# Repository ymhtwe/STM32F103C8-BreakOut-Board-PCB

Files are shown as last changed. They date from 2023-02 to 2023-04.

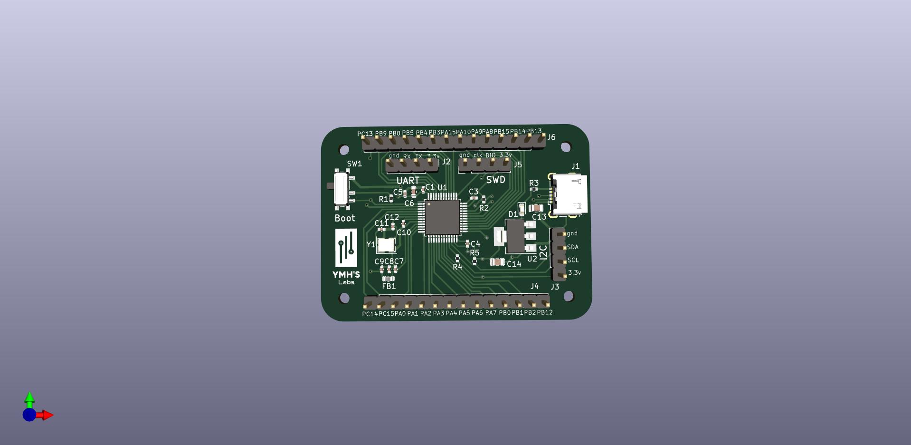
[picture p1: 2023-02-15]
STM32F103C8T6_BreakOut_Board/Docs/STM32 Based 3D.jpg

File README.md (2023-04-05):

# STM32F103C8-BreakOut-Board-PCB 

This repository contains the design files for a breakout board for the STM32F103C8T6 microcontroller in a 48-pin LQFP package. The breakout board provides easy access to all the pins of the microcontroller, as well as a USB-to-serial converter for programming and debugging.

Features
Compact breakout board for the STM32F103C8T6 microcontroller
All pins of the microcontroller are accessible via headers
Onboard 3.3V voltage regulator and decoupling capacitors
USB-to-serial converter for programming and debugging
Bootloader mode for easy firmware updates
Getting started
To get started with the STM32F103C8 Breakout Board PCB, you will need the following:

STM32F103C8T6 microcontroller (not included)
USB-to-serial cable (not included)
Development environment (e.g., STM32CubeIDE, Keil, or Arduino IDE)
To program and debug the microcontroller, connect the USB-to-serial cable to the J1 header on the breakout board, and connect the other end of the cable to your computer. Open your development environment and select the appropriate settings for the microcontroller and programming interface. You can then program and debug your firmware as usual.

Repository contents
Gerber/: Gerber files for manufacturing the PCB
Schematic/: Schematic and BOM for the PCB design
Hardware/: PCB layout design files in KiCad format
License
The STM32F103C8 Breakout Board PCB is released under the MIT License. See the LICENSE file for more details.

Credits
The STM32F103C8 Breakout Board PCB was designed by Ye Min Htwe. If you have any questions or feedback, please open an issue on GitHub.

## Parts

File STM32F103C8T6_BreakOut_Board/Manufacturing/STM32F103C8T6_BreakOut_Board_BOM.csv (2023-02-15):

Source: | E:\KiCad\Projects\STM32F103C8T6_BreakOut_Board\STM32F103C8T6_BreakOut_Board.kicad_sch
Date: | 2/16/2023 3:16:33 AM
Tool: | Eeschema (7.0.0)
Generator: | E:\KiCad\7.0\bin\scripting\plugins/bom_csv_grouped_by_value_with_fp.py
Component Count: | 34
Ref | Qnty | Value | Cmp name | Footprint | Description | Vendor | DNP
C1, C3, C4, C5, C10 | 5 | 100n | C | Capacitor_SMD:C_0402_1005Metric | Unpolarized capacitor
C6 | 1 | 10u | C | Capacitor_SMD:C_0603_1608Metric | Unpolarized capacitor
C7 | 1 | 10n | C | Capacitor_SMD:C_0402_1005Metric | Unpolarized capacitor
C8, C9 | 2 | 1u | C | Capacitor_SMD:C_0402_1005Metric | Unpolarized capacitor
C11, C12 | 2 | 10p | C | Capacitor_SMD:C_0402_1005Metric | Unpolarized capacitor
C13, C14 | 2 | 22u | C | Capacitor_SMD:C_0805_2012Metric | Unpolarized capacitor
D1 | 1 | RED | LED | LED_SMD:LED_0603_1608Metric | Light emitting diode
FB1 | 1 | 1220R | FerriteBead | Inductor_SMD:L_0603_1608Metric | Ferrite bead
H1, H2, H3, H4 | 4 | MountingHole | MountingHole | MountingHole:MountingHole_2.2mm_M2 | Mounting Hole without connection
J1 | 1 | USB_B_Micro | USB_B_Micro | Connector_USB:USB_Micro-B_Wuerth_629105150521 | USB Micro Type B connector
J2, J3, J5 | 3 | Conn_01x04_Pin | Conn_01x04_Pin | Connector_PinHeader_2.54mm:PinHeader_1x04_P2.54mm_Vertical | Generic connector, single row, 01x04, script generated
J4, J6 | 2 | Conn_01x14_Pin | Conn_01x14_Pin | Connector_PinHeader_2.54mm:PinHeader_1x14_P2.54mm_Vertical | Generic connector, single row, 01x14, script generated
R1 | 1 | 10K | R | Resistor_SMD:R_0402_1005Metric | Resistor
R2, R3, R4, R5 | 4 | 1K5 | R | Resistor_SMD:R_0402_1005Metric | Resistor
SW1 | 1 | SW_SPDT | SW_SPDT | Button_Switch_SMD:SW_SPDT_PCM12 | Switch, single pole double throw
U1 | 1 | STM32F103C8T6 | STM32F103C8Tx | Package_QFP:LQFP-48_7x7mm_P0.5mm | STMicroelectronics Arm Cortex-M3 MCU, 64KB flash, 20KB RAM, 72 MHz, 2.0-3.6V, 37 GPIO, LQFP48
U2 | 1 | AMS1117-3.3 | AMS1117-3.3 | Package_TO_SOT_SMD:SOT-223-3_TabPin2 | 1A Low Dropout regulator, positive, 3.3V fixed output, SOT-223
Y1 | 1 | 16 MHz | Crystal_GND24 | Crystal:Crystal_SMD_3225-4Pin_3.2x2.5mm | Four pin crystal, GND on pins 2 and 4

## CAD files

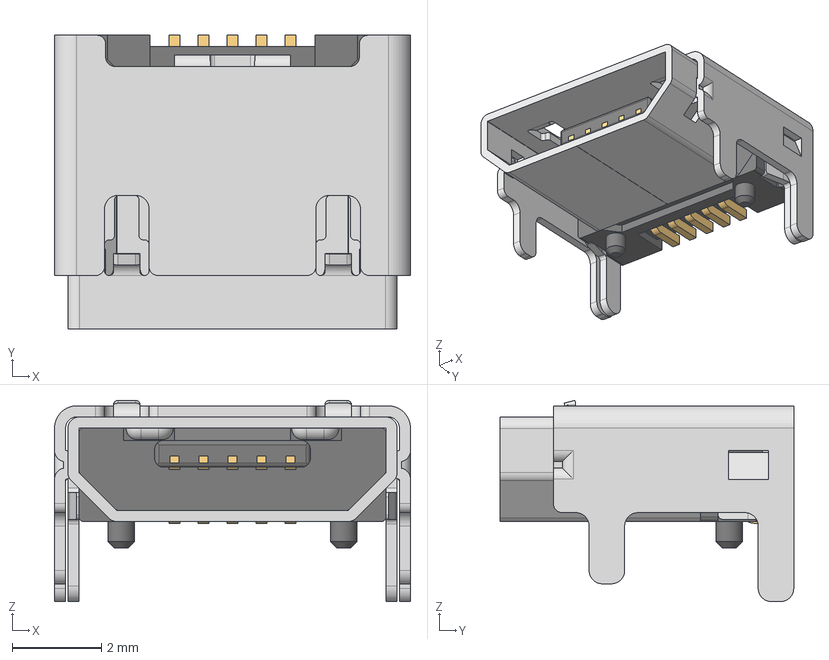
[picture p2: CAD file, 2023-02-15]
STM32F103C8T6_BreakOut_Board/Models/629105150521 (rev1).stp
8.00 x 6.60 x 4.52 mm
629105150521_Housing
629105150521_Pin1 x 4
629105150521_Pin2
629105150521_Shielding2
629105150521_Shielding

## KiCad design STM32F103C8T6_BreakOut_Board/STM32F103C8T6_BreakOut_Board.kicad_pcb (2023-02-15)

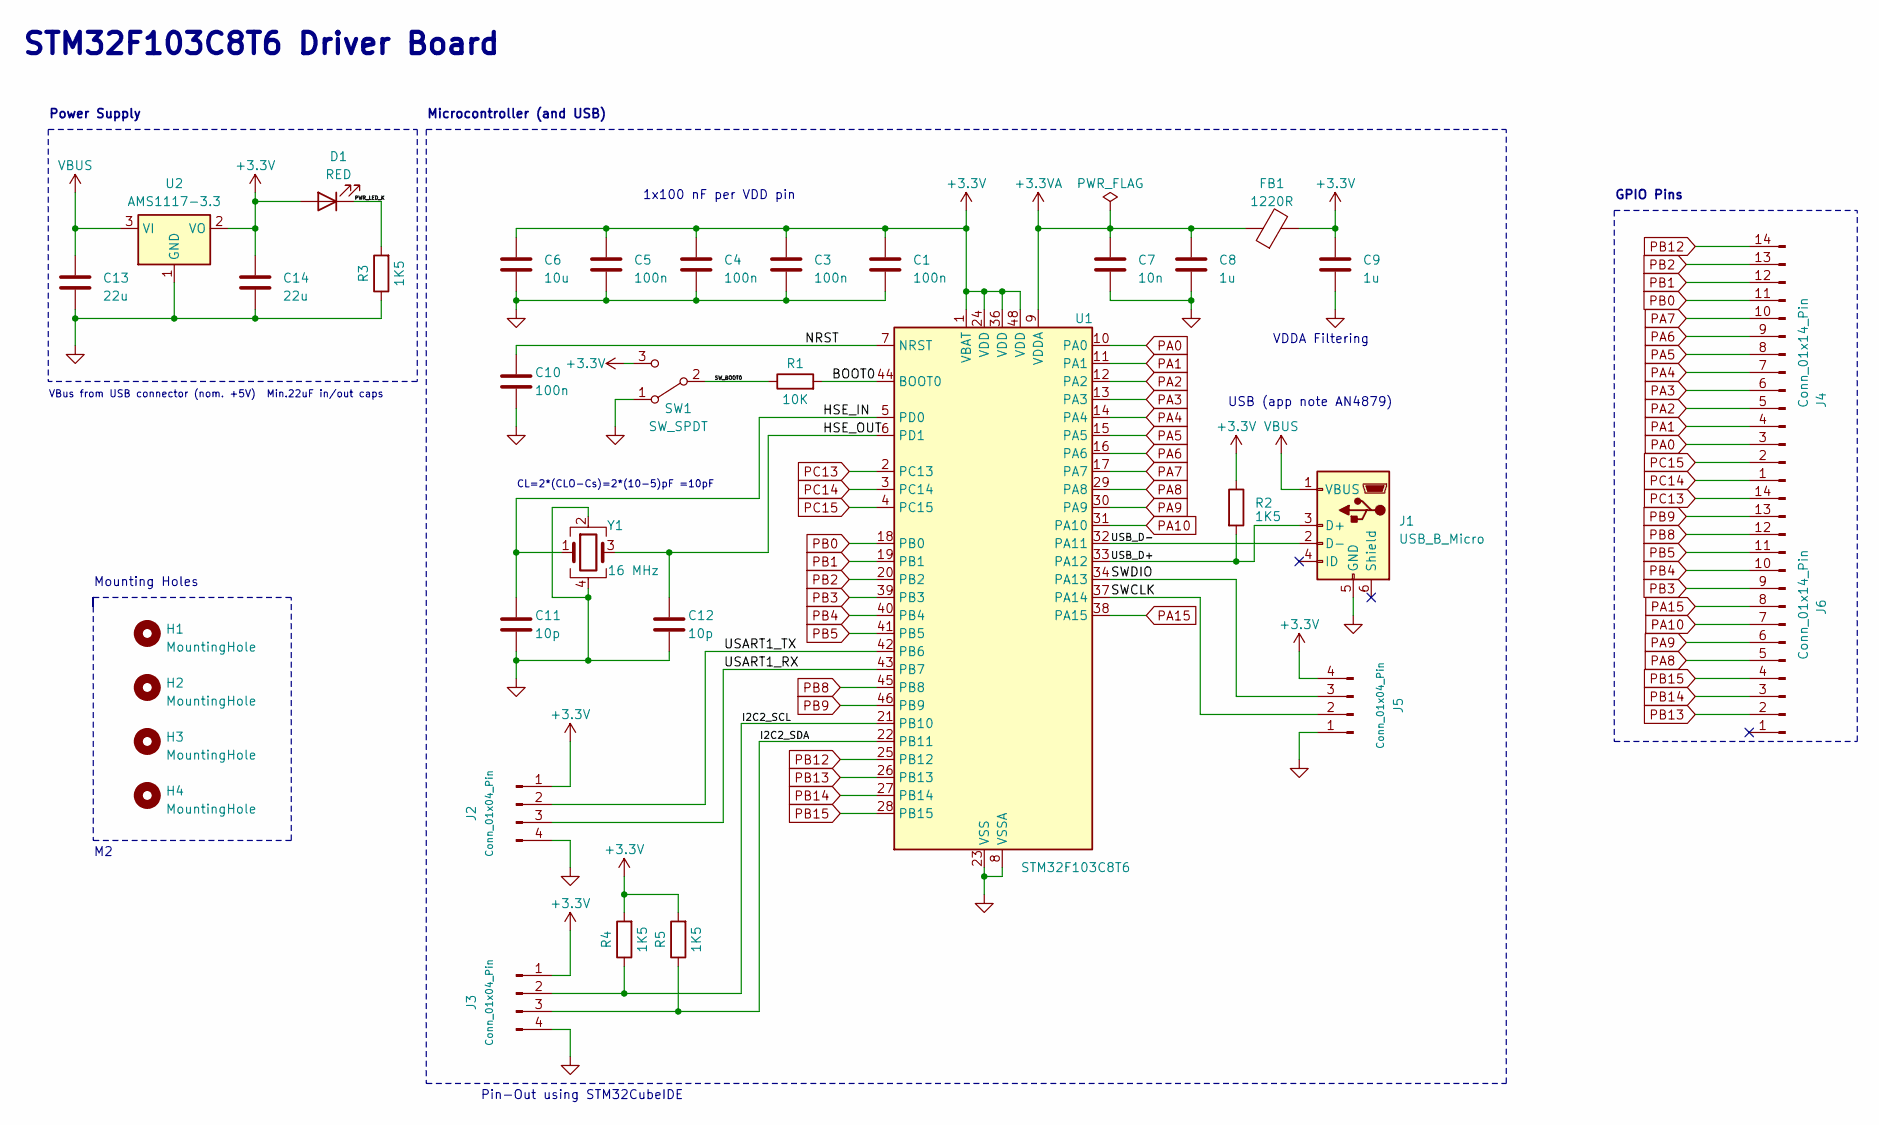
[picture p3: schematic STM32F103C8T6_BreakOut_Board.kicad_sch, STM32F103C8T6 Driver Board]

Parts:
C1, C3, C4, C5, C10: 100n; C_0402_1005Metric
C6: 10u; C_0603_1608Metric
C7: 10n; C_0402_1005Metric
C8, C9: 1u; C_0402_1005Metric
C11, C12: 10p; C_0402_1005Metric
C13, C14: 22u; C_0805_2012Metric
D1: RED; LED_0603_1608Metric
FB1: 1220R; L_0603_1608Metric
H1, H2, H3, H4: MountingHole; MountingHole_2.2mm_M2
J1: USB_B_Micro; USB_Micro-B_Wuerth_629105150521
J2, J3, J5: Conn_01x04_Pin; PinHeader_1x04_P2.54mm_Vertical
J4, J6: Conn_01x14_Pin; PinHeader_1x14_P2.54mm_Vertical
R1: 10K; R_0402_1005Metric
R2, R3, R4, R5: 1K5; R_0402_1005Metric
SW1: SW_SPDT; SW_SPDT_PCM12
U1: STM32F103C8T6; LQFP-48_7x7mm_P0.5mm
U2: AMS1117-3.3; SOT-223-3_TabPin2
Y1: 16 MHz; Crystal_SMD_3225-4Pin_3.2x2.5mm

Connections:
+3.3V: C1.1, C3.1, C4.1, C5.1, C6.1, C9.1, C14.1, D1.2 (A), FB1.2, J2.1, J3.1, J5.4, R2.1, R4.2, R5.2, SW1.3 (C), U1.1 (VBAT), U1.24 (VDD), U1.36 (VDD), U1.48 (VDD), U2.2 (VO)
+3.3VA: C7.1, C8.1, FB1.1, U1.9 (VDDA)
/BOOT0: R1.2, U1.44 (BOOT0)
/HSE_IN: C11.1, U1.5 (PD0), Y1.1
/HSE_OUT: C12.1, U1.6 (PD1), Y1.3
/I2C2_SCL: J3.2, R4.1, U1.21 (PB10)
/I2C2_SDA: J3.3, R5.1, U1.22 (PB11)
/NRST: C10.1, U1.7 (NRST)
/PWR_LED_K: D1.1 (K), R3.2
/SWCLK: J5.2, U1.37 (PA14)
/SWDIO: J5.3, U1.34 (PA13)
/SW_BOOT0: R1.1, SW1.2 (B)
/USART1_RX: J2.3, U1.43 (PB7)
/USART1_TX: J2.2, U1.42 (PB6)
/USB_D+: J1.3 (D+), R2.2, U1.33 (PA12)
/USB_D-: J1.2 (D-), U1.32 (PA11)
GND: C1.2, C3.2, C4.2, C5.2, C6.2, C7.2, C8.2, C9.2, C10.2, C11.2, C12.2, C13.2, C14.2, J1.5 (GND), J2.4, J3.4, J5.1, R3.1, SW1.1 (A), U1.8 (VSSA), U1.23 (VSS), U1.35 (VSS), U1.47 (VSS), U2.1 (GND), Y1.2, Y1.4
PA0: J4.3, U1.10 (PA0)
PA1: J4.4, U1.11 (PA1)
PA2: J4.5, U1.12 (PA2)
PA3: J4.6, U1.13 (PA3)
PA4: J4.7, U1.14 (PA4)
PA5: J4.8, U1.15 (PA5)
PA6: J4.9, U1.16 (PA6)
PA7: J4.10, U1.17 (PA7)
PA8: J6.5, U1.29 (PA8)
PA9: J6.6, U1.30 (PA9)
PA10: J6.7, U1.31 (PA10)
PA15: J6.8, U1.38 (PA15)
PB0: J4.11, U1.18 (PB0)
PB1: J4.12, U1.19 (PB1)
PB2: J4.13, U1.20 (PB2)
PB3: J6.9, U1.39 (PB3)
PB4: J6.10, U1.40 (PB4)
PB5: J6.11, U1.41 (PB5)
PB8: J6.12, U1.45 (PB8)
PB9: J6.13, U1.46 (PB9)
PB12: J4.14, U1.25 (PB12)
PB13: J6.2, U1.26 (PB13)
PB14: J6.3, U1.27 (PB14)
PB15: J6.4, U1.28 (PB15)
PC13: J6.14, U1.2 (PC13)
PC14: J4.1, U1.3 (PC14)
PC15: J4.2, U1.4 (PC15)
VBUS: C13.1, J1.1 (VBUS), U2.3 (VI)

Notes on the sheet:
Microcontroller (and USB)
VDDA Filtering
STM32F103C8T6 Driver Board
Mounting Holes
Pin-Out using STM32CubeIDE
GPIO Pins
Power Supply
VBus from USB connector (nom. +5V) Min.22uF in/out caps
USB (app note AN4879)
1x100 nF per VDD pin
CL=2*(CLO-Cs)=2*(10-5)pF =10pF

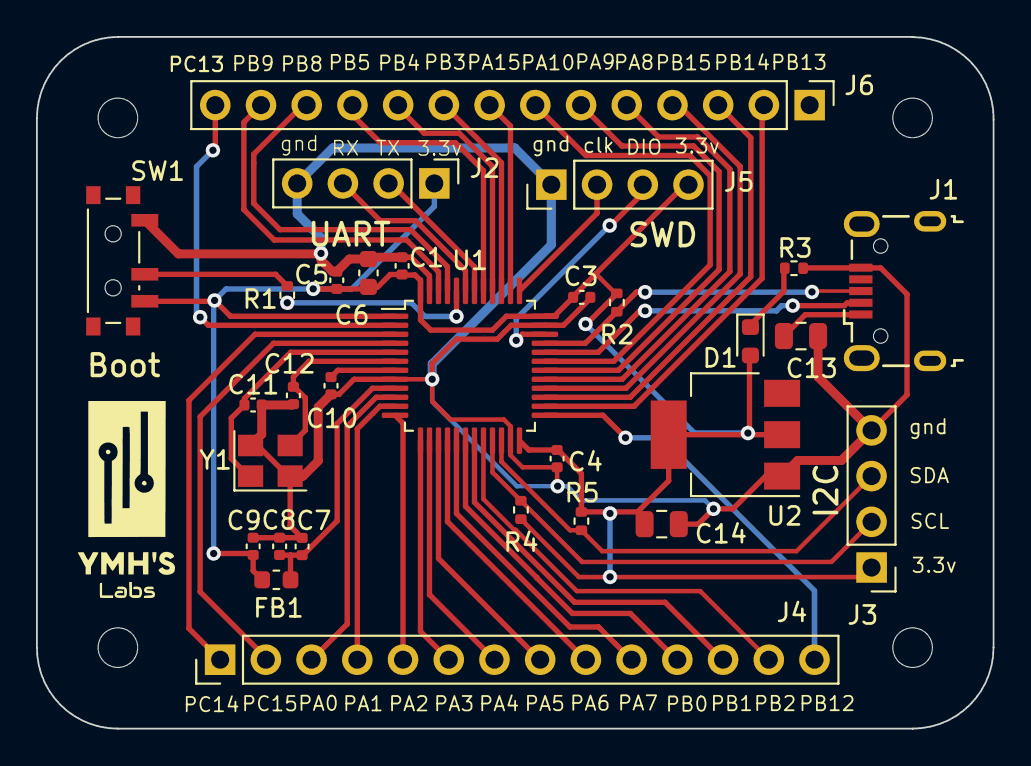
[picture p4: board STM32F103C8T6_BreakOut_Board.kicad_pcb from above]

Board: 2 copper layers, 53.2 x 38.4 mm, 34 parts (0 on the bottom side), 45 nets.
